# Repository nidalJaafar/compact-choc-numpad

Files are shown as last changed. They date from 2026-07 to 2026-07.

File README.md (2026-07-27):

# Compact Choc V2 Numpad



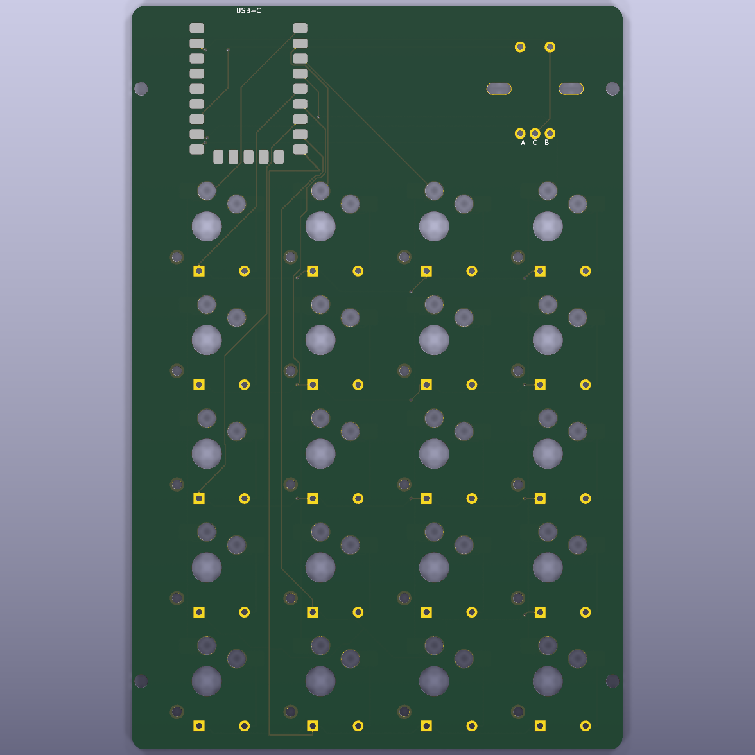
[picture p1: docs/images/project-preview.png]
PCB preview


The locked purchasing list is in [`BOM_FINAL.md`](BOM_FINAL.md).

Pre-generated manufacturing and enclosure files are available from the
[latest GitHub release](https://github.com/nidalJaafar/compact-choc-numpad/releases/latest).

> **Project status:** revision A, not yet physically manufactured. Print and
> test the 1:1 template with the exact purchased parts before ordering PCBs.

Parametric Ergogen source for a compact, wired low-profile numpad with:

- 20 Kailh PG1353 (Choc V2 / "Black Tea") tactile hot-swap positions in a 4-by-5 matrix;
- one headerless Waveshare-compatible RP2040-Zero, soldered by its castellated pads;
- rear-facing USB-C and a vertical 5-pin EC11 push encoder at the rear-right;
- 20 horizontal through-hole 1N4148 DO-35 diodes;
- four M2 mounting holes and 19.05 mm key spacing; and
- an 82.2 by 124.5 mm, 1.6 mm thick, two-layer PCB.

## Firmware: QMK

This wired, USB-first board uses **QMK**. QMK directly supports generic RP2040
boards, matrix scanning, EC11 encoders, and UF2 bootloaders. ZMK can support
RP2040 hardware too, but this particular RP2040-Zero would require additional
board integration and brings no wireless benefit to this design.

The ready-to-copy keyboard definition is in
[`firmware/qmk/compact_choc_numpad`](firmware/qmk/compact_choc_numpad). After
setting up a normal QMK checkout, build it with:

```bash
cp -R firmware/qmk/compact_choc_numpad ~/qmk_firmware/keyboards/
cd ~/qmk_firmware
qmk compile -kb compact_choc_numpad -km default
```

Hold the RP2040-Zero's BOOT button while connecting USB, then copy the produced
`.uf2` file to the `RPI-RP2` drive. The default map uses the encoder for volume,
the encoder push for mute, and places `QK_BOOT` on the Fn layer. See the
[firmware README](firmware/qmk/compact_choc_numpad/readme.md) for the complete
map and flashing notes.

## Repository layout

```text
assets/       Cedar and Beirut engraving artwork
firmware/     QMK keyboard definition and default keymap
footprints/   Project-specific Ergogen footprint generators
scripts/      Routing, case, validation, and fabrication helpers
config.yaml   Parametric Ergogen source of truth
BOM_FINAL.md  Locked purchasing list
```

The controller footprint follows Waveshare's official 18 by 23.5 mm drawing.
Buy the version **without pre-soldered headers** and confirm that any compatible
module has the same dimensions, castellated-pad order, and top-mounted USB-C
connector before soldering it.

## Generate and validate

Install the Node dependencies once:

```bash
npm install --allow-git=all
```

Install the isolated Freerouting bundle once:

```bash
npm run setup:router
```

Generate the PCB, route it, and regenerate both enclosure STLs:

```bash
npm run generate
```

The principal PCB result is:

```text
output/pcbs/compact_choc_numpad-routed.kicad_pcb
```

Run the checks and exports with:

```bash
npm run validate
npm run render
npm run print:1to1
npm run gerbers
```

`npm run validate` first synchronizes five exact embedded footprint definitions
into `output/pcbs/CompactNumpad.pretty` and relinks both PCB files through the
project-local `fp-lib-table`. The routed board then passes KiCad DRC with zero
violations, zero unconnected pads, and zero footprint errors. This validates
the actual embedded geometry without suppressing library checks.

The JLCPCB-ready fabrication archive is written to
`output/compact_choc_numpad-gerbers.zip`. It contains the two copper layers,
two solder-mask layers, two silkscreen layers, board outline, Gerber job file,
and separate plated and non-plated Excellon drill files.

## Releases

Generated hardware files are not committed to the repository. Pushing a tag
such as `v0.4.0` runs the full routing, DRC, enclosure, rendering, and export
pipeline and publishes a GitHub Release containing:

- JLCPCB-ready Gerbers;
- routed and unrouted KiCad projects with exact local footprints;
- printable top-cover and bottom-tray STLs;
- a true-scale fit-check PDF;
- PCB and enclosure previews;
- an Ergogen web-editor bundle;
- QMK source, BOM, documentation, and SHA-256 checksums; and
- one complete ZIP containing the full release set.

Release files are generated from the tagged source in a clean GitHub runner.
They remain revision-A artifacts until the physical component fit checks in
this README have been completed.

## GPIO assignment

```text
GP0..GP3  COL0..COL3
GP4..GP8  ROW0..ROW4
GP14      encoder A
GP15      encoder B
GP26      encoder push
GND       encoder common and push return
```

The matrix is `COL2ROW`. The RP2040-Zero's own BOOT and RESET buttons remain
under the removable cover; there is no separate reset switch or reset opening.

## Low-profile enclosure

Generate only the Ergogen layout and enclosure with:

```bash
npm run generate:case
```

This creates:

```text
output/stl/bottom_tray.stl
output/stl/top_cover.stl
```

The tray is 13.4 mm high with a 1.6 mm floor and 3.5 mm PCB supports. The PCB
underside sits 5.1 mm above the base, leaving about 0.45 mm below the nominal
3.05 mm Choc socket envelope. The rear controller band remains 15.4 mm high
when assembled, but the complete key deck and the front/side tray walls are
stepped down by 4.4 mm. The key deck therefore sits at approximately 11 mm
above the base and exposes about 4.3 mm of the nominal PG1353 switch housing.
This is the practical minimum for the present 1.6 mm PCB, underside sockets,
through-hole diodes, RP2040-Zero, and standard EC11 body: the design allowance
above the nominal
encoder body is only about 0.2 mm. The cover retains 20 individual 16.2 mm
switch openings and 2.85 mm plastic webs between adjacent openings; it is not
one large PCB-exposing cutout. It also has an encoder opening and shallow
recessed Lebanese cedar and Beirut calligraphy engravings. USB-C access is
through a compact 11 x 6 mm window in the rear wall of the bottom tray, while
the top cover remains closed at the rear.

The cedar is generated from `assets/cedar-traced.svg`, and the Beirut
calligraphy from `assets/beirut-traced.svg`. These smooth vector traces are
sampled at approximately 0.09 mm for robust watertight booleans without visible
raster stair-stepping in the printed part. The cedar artwork is derived from
the public-domain Lebanese flag by Henri Pharaon.

Print the tray floor-down. Because the exposed-switch cover has two deck
heights, print it upright on one long edge with a brim, or use slicer-generated
supports; it no longer has one broad planar exterior face. Use a low-profile
knob for a 6 mm shaft and thin (about 1 mm) rubber feet. The purchased DSA
keycaps are taller than the custom 6 mm prototype cap, so they—not the
enclosure—will set much of the finished height. Test one keycap for skirt
clearance and stem fit first.

## Ergogen web editor

Upload `output/compact_choc_numpad-ergogen-bundle.zip`, not `config.yaml`
alone. The ZIP includes all project-specific footprint scripts.

## Before manufacturing

Print `output/pdf/compact_choc_numpad-1to1.pdf` at **100% / Actual size** and
test real samples of the PG1353 switch, matching Choc socket, RP2040-Zero,
encoder, and diode. Select the listing's vertical five-pin push encoder with
the **12 mm full shaft** specified in the BOM. The universal PCB slots accept
common EC11 and PEC11R mounting tabs, but the listing's exact pin and tab
dimensions must still be checked on the paper print. The PG1353/socket
combination uses a community-derived geometry and should be physically
test-fitted before ordering the full BOM.

## Contributing

Bug reports and pull requests are welcome. Read [`CONTRIBUTING.md`](CONTRIBUTING.md)
before changing mechanical dimensions or footprint geometry. Generated files
under `output/` are intentionally not committed; GitHub Actions regenerates the
core layout from source on every push and pull request.

## License

No project-wide open-source license has been selected yet. Until the owner adds
one, the original project files are all rights reserved. Third-party assets and
vendored libraries retain their own licenses and attribution; see
[`THIRD_PARTY_NOTICES.md`](THIRD_PARTY_NOTICES.md).

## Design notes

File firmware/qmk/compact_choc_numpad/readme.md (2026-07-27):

# Compact Choc Numpad QMK firmware

This definition targets the headerless Waveshare-compatible RP2040-Zero used
by the PCB. It matches the hardware nets in `config.yaml`:

| Function | Pin |
| --- | --- |
| Columns 0–3 | GP0–GP3 |
| Rows 0–4 | GP4–GP8 |
| Encoder A / B | GP14 / GP15 |
| Encoder push | GP26 to GND |

The matrix uses `COL2ROW`. Encoder push is a direct active-low input handled by
QMK's dip-switch scanner; despite the subsystem name, a momentary switch wired
from the configured pin to ground is supported.

## Build

Install QMK by following its official setup guide, then copy this directory
into the root of the QMK keyboard tree:

```bash
cp -R firmware/qmk/compact_choc_numpad ~/qmk_firmware/keyboards/
cd ~/qmk_firmware
qmk compile -kb compact_choc_numpad -km default
```

The default keymap is:

```text
[ Num ] [  /  ] [  *  ] [  -  ]
[  7  ] [  8  ] [  9  ] [  +  ]
[  4  ] [  5  ] [  6  ] [  =  ]
[  1  ] [  2  ] [  3  ] [Enter]
[  0  ] [  .  ] [Back ] [ Fn  ]
```

The encoder controls volume, and its push switch sends mute. The Fn layer adds
navigation keys and `QK_BOOT` at the upper-left position.

## Flash

Hold BOOT while connecting USB, or double-tap RESET, and copy the generated
UF2 to the `RPI-RP2` drive. No dedicated reset switch is present on the PCB;
the controller module's onboard buttons remain available under the removable
cover.

The `0xFEED:0x2040` USB identifier is suitable for personal development only.
Choose an appropriately assigned VID/PID before distributing a commercial
product.

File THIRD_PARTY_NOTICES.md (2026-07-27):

# Third-party notices

## Ergogen ceoloide footprints

The files under `footprints/ceoloide/` come from
[`ceoloide/ergogen-footprints`](https://github.com/ceoloide/ergogen-footprints)
and are distributed under the MIT License. The copyright and full license text
are retained in [`footprints/ceoloide/LICENSE`](footprints/ceoloide/LICENSE).

## Lebanese cedar artwork

The artwork used to derive the cedar engraving is identified as public domain
in the project documentation. Confirm the status of any replacement artwork
before redistributing it.

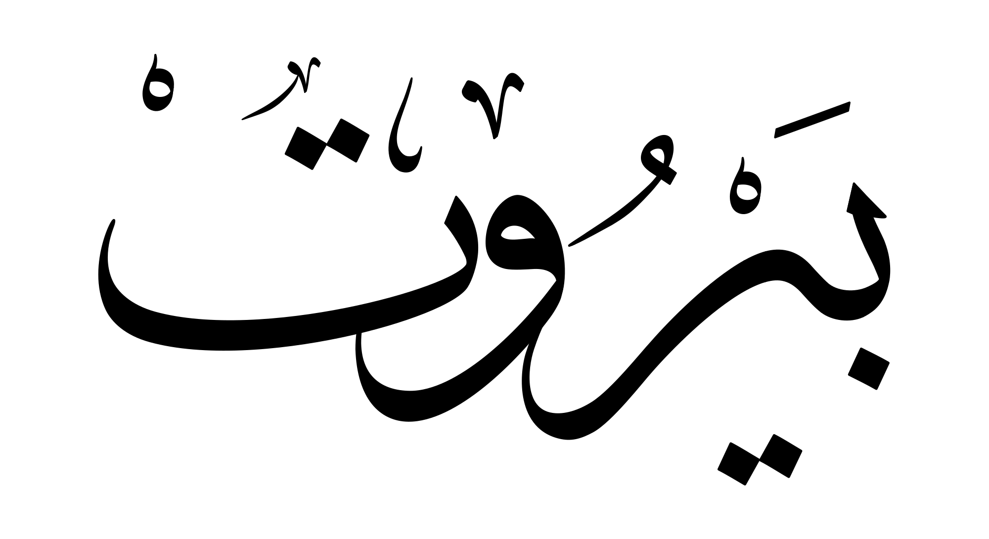
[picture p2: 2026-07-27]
assets/beirut.png

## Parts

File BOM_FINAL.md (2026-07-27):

# Final locked BOM

**Project:** Compact wired low-profile PG1353 tactile numpad  
**Locked:** 2026-07-27  
**Status:** Final purchasing list supplied by the project owner

| Item | Required for one build | Purchase quantity | Spare quantity | Supplier |
|---|---:|---:|---:|---|
| RP2040-Zero development board, headerless | 1 | 3 | 2 | [ChiBox](https://chibox.app/products/p-754141514242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) |
| Kailh PG1353 ("Black Tea") tactile switches | 20 | 22 | 2 | [ChiBox](https://chibox.app/products/p-845942737255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) |
| Kailh PG1353-compatible hot-swap sockets | 20 | 30 | 10 | [ChiBox](https://chibox.app/products/p-813551952580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) |
| EC11 vertical rotary encoder with push switch, 12 mm full shaft | 1 | 3 | 2 | [ChiBox](https://chibox.app/products/p-978134519093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) |
| 1N4148 axial diodes, DO-35 | 20 | 1 pack (100) | 80 | [ChiBox](https://chibox.app/products/p-984740882379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) |
| DSA low-profile dome keycaps, 1u MX cross mount | 20 | 20 | 0 | [ChiBox](https://chibox.app/products/p-730718564588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) |

## PCB and case

| Item | Specification |
|---|---|
| PCB | JLCPCB, 5 boards, 2 layers, 1.6 mm FR-4, black or white solder mask |
| Case | Local 3D print, PLA or PETG |
| Feet | 4 thin self-adhesive rubber feet, preferably about 1 mm thick |
| Cable | USB-C data cable |

## Locked compatibility requirements

- Buy the RP2040-Zero **without installed headers**. It must match the PCB's 18 x 23.5 mm Waveshare-compatible outline, castellated-pad order, and top-mounted USB-C position.
- The switch selection must be the **PG1353 tactile / Black Tea** variant with an MX-style cross stem. Confirm the variant shown in the ChiBox cart before checkout.
- The sockets must be the matching **Kailh Choc/PG1353 low-profile hot-swap** type, not an MX hot-swap socket.
- Select a **vertical five-pin EC11 with push switch and 12 mm full shaft**. The linked product title mentions multiple shaft sizes/styles, so verify the selected cart variant. The PCB's elongated anchor slots accept common EC11 and PEC11R tab spacings, but the pin geometry must be checked against the 100% print.
- The diodes must be axial **1N4148 in DO-35 packaging**, not an SMD version.
- Select the linked listing's **1u** option with an **MX cross mount**. The listing covers multiple sizes and colors, so verify the cart variant before checkout. Test one cap first: PG1353 stem engagement and the keycap skirt's clearance over the low-profile switch must still be confirmed physically.

## Cost snapshot supplied with this BOM

| Item | Estimated cost |
|---|---:|
| ChiBox products | $21.18 |
| China local delivery | $3.78 |
| Sea freight | $4.82 |
| Delivered to Lebanon | about $29.78 |
| JLCPCB, 5 boards | about $5 |
| Local printed case | about $5–15 |
| Complete project | about $40–50 |

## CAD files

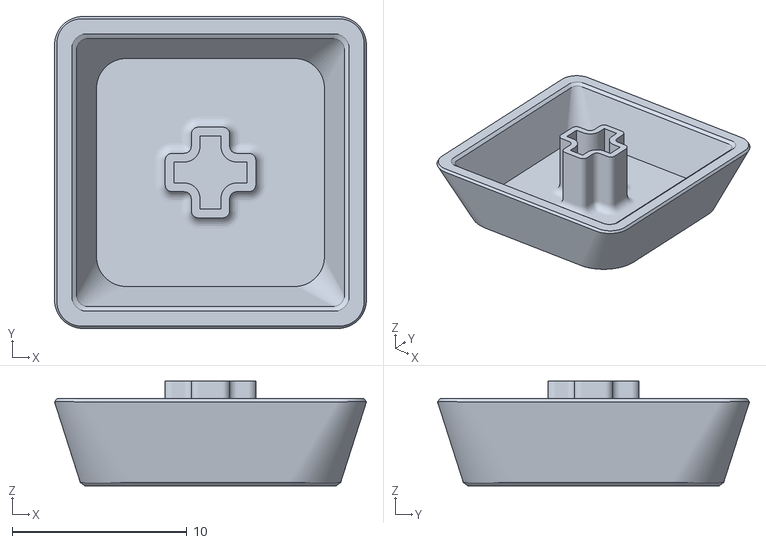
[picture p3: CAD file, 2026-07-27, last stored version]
assets/keycap.stl
17.9 x 17.9 x 6.00

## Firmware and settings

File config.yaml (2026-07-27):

meta:
  engine: 4.2.1
  name: compact_choc_numpad
  version: 0.4.0
  author: nidal

units:
  kx: 19.05
  ky: 19.05
  board_margin: 2
  case_wall: 2.2
  case_clearance: 0.35
  case_floor: 1.6
  case_height: 13.4
  exposed_wall_height: 9
  pcb_support_height: 3.5
  case_boss_radius: 3.4
  case_pilot_radius: 0.85
  frame_height: 2
  frame_lip_height: 1.2
  cover_switch_cutout: 16.2
  cover_encoder_radius: 4
  usb_notch_width: 11
  usb_notch_depth: 5
  usb_notch_floor: 5.6
  usb_notch_height: 6

points:
  zones:
    matrix:
      key:
        spread: kx
        padding: ky
        tags: [key]
      columns:
        c0:
          key:
            column_net: COL0
        c1:
          key:
            column_net: COL1
        c2:
          key:
            column_net: COL2
        c3:
          key:
            column_net: COL3
      rows:
        r4:
          row_net: ROW4
        r3:
          row_net: ROW3
        r2:
          row_net: ROW2
        r1:
          row_net: ROW1
        r0:
          row_net: ROW0

outlines:
  keys:
    - what: rectangle
      where: key
      size: [kx, ky]
  board:
    - what: rectangle
      where:
        ref: matrix_c1_r2
        shift: [9.525, 12.75]
      size: [82.2, 124.5]
      fillet: 2

  # Private outlines used to construct the two-piece printed enclosure.
  _case_outer:
    - name: board
      expand: case_wall + case_clearance
      fillet: 3
  _case_cavity:
    - name: board
      expand: case_clearance
      fillet: 2.25
  _frame_lip_outer:
    - name: board
      expand: case_clearance - 0.2
      fillet: 2.1
  _frame_opening:
    - name: board
      expand: -1.7
      fillet: 1
  _case_bosses:
    - what: circle
      where:
        ref: matrix_c0_r4
        shift: [-11, 99.25]
      radius: case_boss_radius
    - what: circle
      where:
        ref: matrix_c3_r4
        shift: [10.85, 99.25]
      radius: case_boss_radius
    - what: circle
      where:
        ref: matrix_c0_r4
        shift: [-11, 0]
      radius: case_boss_radius
    - what: circle
      where:
        ref: matrix_c3_r4
        shift: [10.85, 0]
      radius: case_boss_radius
  _case_pilot_holes:
    - what: circle
      where:
        ref: matrix_c0_r4
        shift: [-11, 99.25]
      radius: case_pilot_radius
    - what: circle
      where:
        ref: matrix_c3_r4
        shift: [10.85, 99.25]
      radius: case_pilot_radius
    - what: circle
      where:
        ref: matrix_c0_r4
        shift: [-11, 0]
      radius: case_pilot_radius
    - what: circle
      where:
        ref: matrix_c3_r4
        shift: [10.85, 0]
      radius: case_pilot_radius
  # Enclosed rear-wall window aligned with the RP2040-Zero USB-C connector.
  _usb_notch:
    - what: rectangle
      where:
        ref: matrix_c0_r4
        shift: [7, 113.5]
      size: [usb_notch_width, usb_notch_depth]
  _cover_switch_openings:
    - what: rectangle
      where: key
      size: [cover_switch_cutout, cover_switch_cutout]
  # Lowers only the key-field walls. The rear controller/encoder compartment
  # remains full height, producing an exposed-switch floating-key profile.
  _key_field_lowering:
    - what: rectangle
      where:
        ref: matrix_c1_r2
        shift: [9.525, -6.6]
      size: [100, 113]
  _cover_encoder_opening:
    - what: circle
      where:
        ref: matrix_c3_r4
        shift: [-2.15, 99.25]
      radius: cover_encoder_radius
cases:
  _bottom_shell:
    outer:
      what: outline
      name: _case_outer
      extrude: case_height
    cavity:
      what: outline
      name: _case_cavity
      extrude: case_height - case_floor
      shift: [0, 0, case_floor]
      operation: subtract
  _bottom_with_bosses:
    shell:
      what: case
      name: _bottom_shell
    bosses:
      what: outline
      name: _case_bosses
      extrude: pcb_support_height
      shift: [0, 0, case_floor]
      operation: add
  _bottom_stepped:
    body:
      what: case
      name: _bottom_with_bosses
    lowered_key_field:
      what: outline
      name: _key_field_lowering
      extrude: case_height - exposed_wall_height
      shift: [0, 0, exposed_wall_height]
      operation: subtract
  bottom_tray:
    body:
      what: case
      name: _bottom_stepped
    pilot_holes:
      what: outline
      name: _case_pilot_holes
      extrude: case_floor + pcb_support_height
      operation: subtract
    usb_notch:
      what: outline
      name: _usb_notch
      extrude: usb_notch_height
      shift: [0, 0, usb_notch_floor]
      operation: subtract
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

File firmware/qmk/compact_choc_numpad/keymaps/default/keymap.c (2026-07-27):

#include QMK_KEYBOARD_H

enum layers {
    _BASE,
    _FN,
};

const uint16_t PROGMEM keymaps[][MATRIX_ROWS][MATRIX_COLS] = {
    [_BASE] = LAYOUT_ortho_5x4(
        KC_NUM,  KC_PSLS, KC_PAST, KC_PMNS,
        KC_P7,   KC_P8,   KC_P9,   KC_PPLS,
        KC_P4,   KC_P5,   KC_P6,   KC_PEQL,
        KC_P1,   KC_P2,   KC_P3,   KC_PENT,
        KC_P0,   KC_PDOT, KC_BSPC, MO(_FN)
    ),
    [_FN] = LAYOUT_ortho_5x4(
        QK_BOOT, XXXXXXX, XXXXXXX, XXXXXXX,
        KC_HOME, KC_UP,   KC_PGUP, _______,
        KC_LEFT, XXXXXXX, KC_RGHT, _______,
        KC_END,  KC_DOWN, KC_PGDN, _______,
        _______, KC_DEL,  KC_MUTE, _______
    ),
};

#if defined(ENCODER_MAP_ENABLE)
const uint16_t PROGMEM encoder_map[][NUM_ENCODERS][NUM_DIRECTIONS] = {
    [_BASE] = {ENCODER_CCW_CW(KC_VOLD, KC_VOLU)},
    [_FN]   = {ENCODER_CCW_CW(KC_PGDN, KC_PGUP)},
};
#endif

// The encoder's momentary push switch is wired directly from GP26 to ground.
bool dip_switch_update_user(uint8_t index, bool active) {
    if (index == 0 && active) {
        tap_code16(KC_MUTE);
    }
    return true;
}

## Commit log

2026-07-27 hardware: Add compact Choc numpad design
    * Include parametric PCB, low-profile enclosure, and locked BOM
    * Add QMK firmware, reproducible build scripts, and fabrication checks
    * Add GitHub CI, secret scanning, and contributor documentation
    [keycap.stl]
2026-07-27 assets: Remove unused reference models
    [keycap.stl]
2026-07-27 build: Support ImageMagick 6 case generation
